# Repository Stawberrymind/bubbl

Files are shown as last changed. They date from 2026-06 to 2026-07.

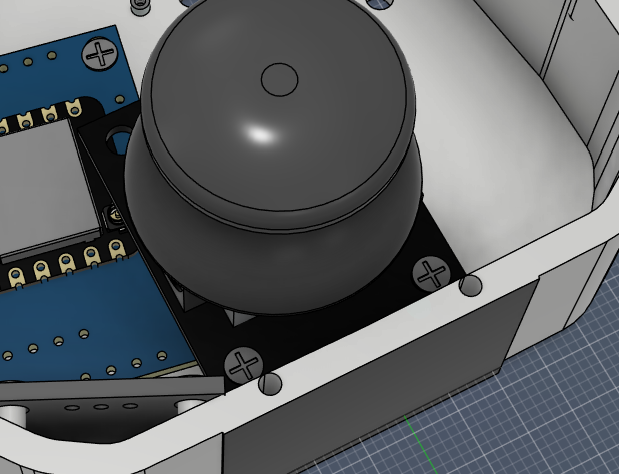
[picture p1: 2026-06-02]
Assets/assembly_2.png

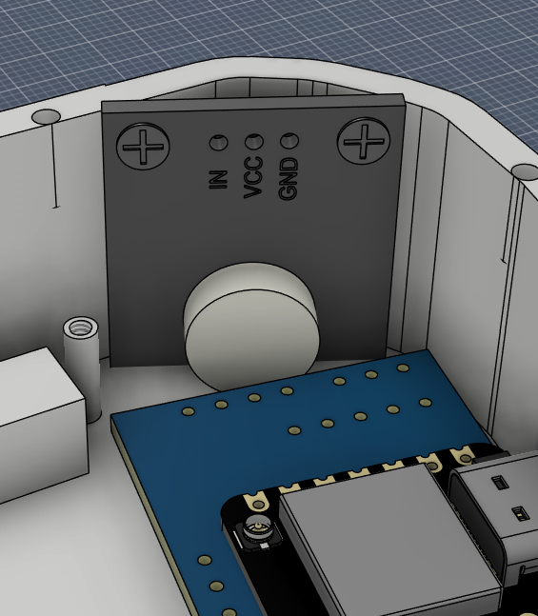
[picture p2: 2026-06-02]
Assets/assembly_1.png

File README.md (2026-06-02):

bubbl_assembled

# bubbl- A tamagotchi-inspired desk pet to keep friendships alive.

A friendship-powered Tamagotchi-inspired pet for your desk, which looks like a Japanese onigiri, keeps friend groups alive by maintaining a common pet and sending nudges to each other, just to keep the drifting friend group a little closer! 

## How does it work?
There is one shared pet for everyone. Every bubbl device in the same group (friend group) has the same pet, you can feed the pet, make it rest, and play with it. If no one in the friend group interacts with the pet, the pet's stats decay, causing harm to it :(, which incentivises the friend group to keep interacting with the pet. In the process, friends can send each other nudges, which are sound notifcations which also vibrate the device; this is useful when. This adds a fun component to the already interesting and interactive interconnected pet system. 

## Why did I make it?
In the current day and age, where friendships are basically just sending each other reels, friendships are dying fast. There is no real connection, and bubbl I hope helps solve that issue by having a pet to take care of; it makes sure all the members of the friend group have equal responsibility and are constantly reminded of each other, thus hopefully reducing friction in friendships.
 
## Components Required for the Build
I have listed everything in the project; you can find the same in the BOM

| No. | Quantity | Comment | Footprint | Link | Price | Total (USD) |
| ----- | --- | --- | --- | --- | ----- | --- |
| 1 | 1 | XIAO-ESP32-S3-SMD | XIAO-ESP32-S3-SMD | https://www.aliexpress.com/item/1005006987905528.html | 6.77  | 6.77 |
| 2 | 2 | 10uF | C0603 | https://jlcpcb.com/partdetail/HRE-CGA0805X5R106K500MT/C6119889 | 0.01  | 0.02 |
| 3 | 2 | 100nF | C0603 | https://jlcpcb.com/partdetail/39123-0805B104K500NT/C38141 | 0.01  | 0.02 |
| 4 | 1 | MAX98357A | \- | https://www.aliexpress.com/item/1005007003802663.html | 0.65  | 0.65 |
| 5 | 1 | INMP441 | \- | https://www.aliexpress.com/item/1005008870682636.html | 0.75  | 0.75 |
| 6 | 1 | 1.3" OLED | \- | https://www.aliexpress.com/item/1005008365029314.html | 2.03  | 2.03 |
| 7 | 1 | Analog Joystick Module | \- | https://www.aliexpress.com/item/1005012147405483.html | 1.92  | 1.92 |
| 8 | 1 |  Vibration Motor Module | \- | https://www.aliexpress.com/item/33009331080.html | 0.49  | 0.49 |
| 9 | 10 | M2 X 3mm Phillips Round head | \- | https://onlyscrews.in/products/m2-x-5mm-phillips-round-head-laptop-screw | 0.04  | 0.4 |
| 10 | 5 | M1.4 X 2mm Phillips Round head | \- | https://onlyscrews.in/products/m1-4-x-2mm-phillips-round-head-laptop-and-mobile-screw-dia-1-4mm-length-2mm | 0.023 | 0.115 |
| 11 | 6 | M2 X 10mm Hard Dowel Pins | \- | https://onlyscrews.in/products/m2-x-10mm-hard-dowel-pins-dia-2mm-length-10mm | 0.051 | 0.306 |
| 12 | 1 | 400mAh LiPo | \- | https://robu.in/product/400mah-pcm-protected-micro-li-po-battery-2/ | 2.86  | 2.86 |
| 13 | 5 | 2 Layer PCB | \- | https://cart.jlcpcb.com/quote?spm=jlcpcb.Public.2006 | 2.1 | 2.1 |
| Total | | | | | | 18.431 USD  |

## PCB and Schematic
I designed it in EasyEDA. You can find the Gerber files in the repo. The schematic is:

schematic

And the PCB is a 2-layer PCB with a ground plane as layer 2:

pcb

3D Render of the PCB:

pcb_3d

Wiring diagram:

wiring_diagram

## Case
Top and bottom view of the Case:

case_front_back

## Assembly 
Note: Please follow the wiring diagram :)
1. Take the bottom case and install the PCB, and screw it into the bottom case using a M2 x 3 mm screw. Before screwing it, wire the BAT+ and BAT- from LiPO to the PCB.

2. Screw in the Vibration motor after making the connections, as shown in the picture, using M2 x 3 mm

   assembly_1
 
3. Wire the Joystick Module to the PCB, then screw it in using M2 x 3 mm screws as shown in the picture.

   assembly_2

5. Screw in the Speaker, with the diaphragm facing outward towards the speaker holes, using a M2 X 3 mm screw as shown in the picture.
 
   assembly_3

6. Connect the amplifier to the microcontroller, then screw the amp into the case using  M1.4 x 2 mm screws as shown. Then connect the speaker to the amplifier.
   
   assembly_4
   
7. The bottom of the case should now look as shown below.
   
   assembly_5

8. Insert M2 x 10 mm hard metal dowel pins into the bottom case as shown below.
   
   assembly_6

9. Now it's time to assemble the top case, screw in the OLED to the underside of the top case using M2 x 3 mm screws as shown and wire it to the microcontroller.

   assembly_7

10. Install the INMP441 I2S Microphone with M1.4 x 2 mm screws into the case as shown and wire it to the microcontroller.
 
   assembly_8

11. Lower the top case onto the bottom one, applying firm pressure equally from all sides to make sure the top locks in with the bottom using the dowel pins.
12. Your own personal bubbl is now complete!

## Setting it up
Section I: Setting up Supabase:
1. Go to https://supabase.com/ and create a new account
2. Create a new project

   

4. Go to the SQL Editor Tab and paste the content of the bubbl_supabase file in Firmware into the editor

   

5. Run the script, which will lead to the creation of the following tables: pet, users, events, and nudges
6. In the SQL Editor, enter your friends' names in place of user1...4

7. Go to your Supabase settings, then to API and copy your:
   * Project URL
   * Anom public key

Section II: Setting up the firmware:

7.  In the bubbl.ino file, replace the SSID and password fields with your credentials, enter the Supabase URL and Anon Key below, and set up your name.
   * Note: All friends must use the same project
   * Be listed in the users table
   * Have a unique username

8. Install the required libraries and upload the firmware to bubbl

9. Wohooooo! You and your friend group now have a working bubbl of your own!

## Files
```text
    └── bubbl/
        ├── CAD_Files/
        │   ├── bubbl_case.step
        |   ├── bubbl.stl
        │   ├── bubbl_assembled.f3z
        │   └── bubbl_assembled.step
        ├── PCB_Files/
        │   ├── bubbl_gerber.zip
        │   └── bubbl_source.epro2
        ├── Firmware_Files/
        │   ├── bubbl.ino
        │   ├── bubbl_supabase.mdf
        │   └── bubbl.wav
        ├── bubbl_BOM.csv
        ├── bubbl_Zine.pdf
        └── README.md
        └── Assets/
        
```
## Future Additions
In upcoming software versions, I will include support to send short voice notes to your buddies!

## Credits

Abhinav [goat]

The idea: https://github.com/TaniWanKenobi/tamagotchi

Vibration motor module: https://grabcad.com/library/vibration-motors-1

OLED module: https://grabcad.com/library/oled-display-1-3-2

Amplifier: https://grabcad.com/library/max98357a-3w-i2s-amplifier-1

Microphone: https://grabcad.com/library/inmp441-microphone-module-1

Joystick: https://grabcad.com/library/dual-axis-xy-joystick-module-with-push-button-1

## Zine

bubbl_zine

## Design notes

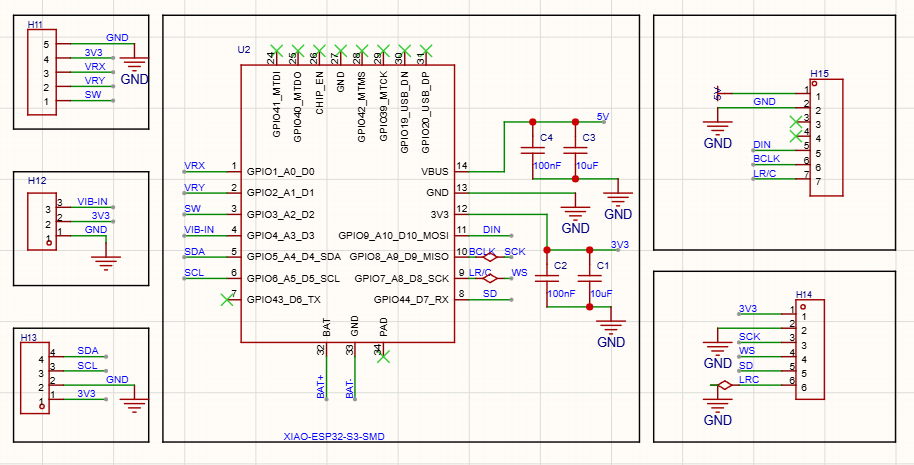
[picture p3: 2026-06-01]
Assets/schematic.png

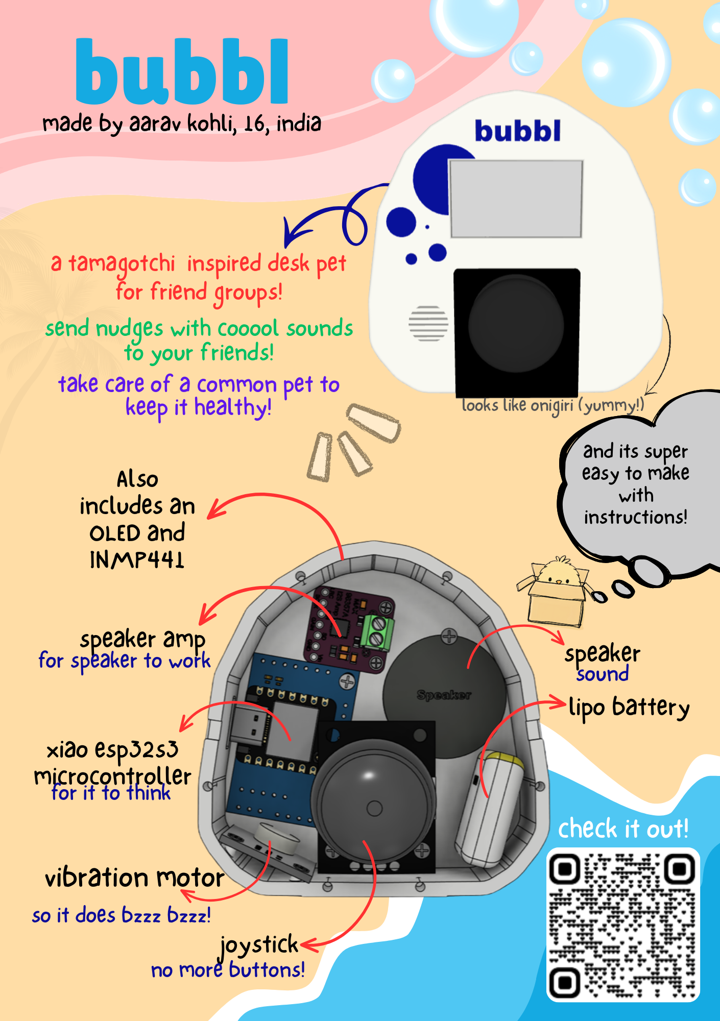
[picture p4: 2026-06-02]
Assets/bubbl_zine.png

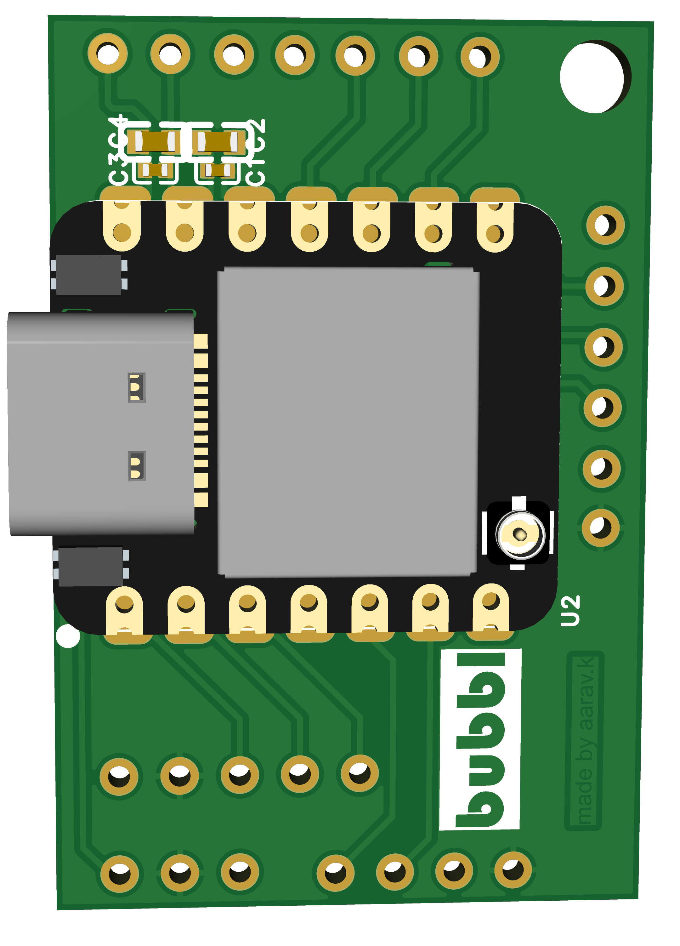
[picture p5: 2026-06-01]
Assets/pcb_3d.png

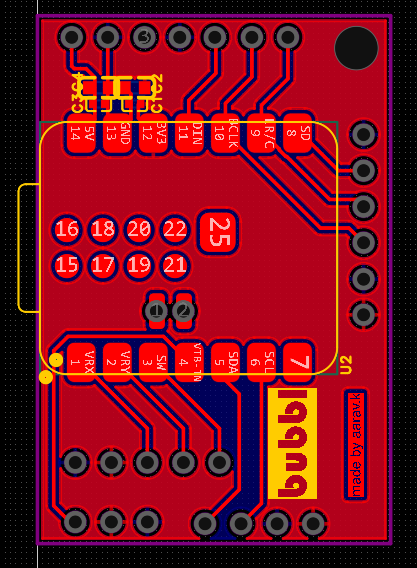
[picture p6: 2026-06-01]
Assets/pcb.png

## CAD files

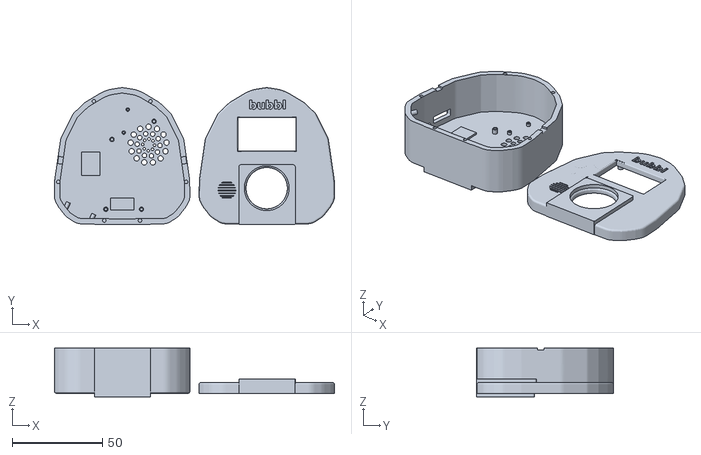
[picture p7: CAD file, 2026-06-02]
CAD_Files/bubbl.stl
154.9 x 75.6 x 27.0

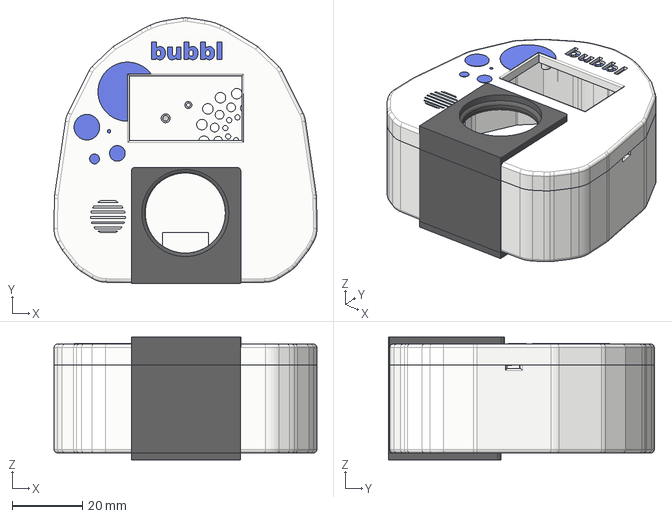
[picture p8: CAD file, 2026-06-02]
CAD_Files/bubbl_case.step
74.9 x 75.6 x 35.0 mm

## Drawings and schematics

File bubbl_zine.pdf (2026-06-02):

# bubbl

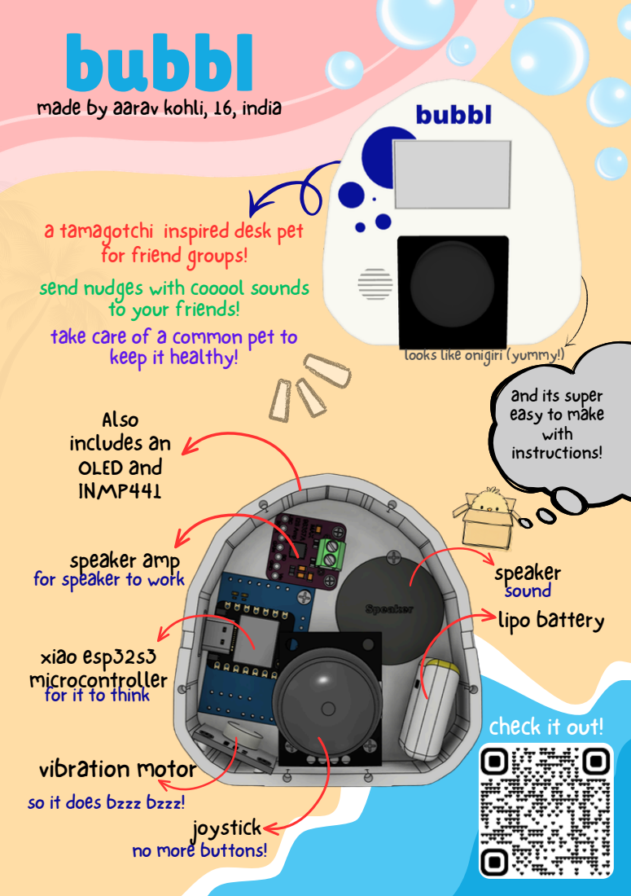
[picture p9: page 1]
joystick; speaker lipo battery; sound

made by aarav kohli, 16, india

a tamagotchi inspired desk pet
for friend groups!
send nudges with cooool sounds
to your friends!
take care of a common pet to
keep it healthy!
Also
includes an
OLED and
INMP441
speaker amp
for speaker to work
xiao esp32s3
microcontroller
for it to think
vibration motor
so it does bzzz bzzz!
no more buttons!

looks like onigiri (yummy!)

and its super
easy to make
with
instructions!

check it out!

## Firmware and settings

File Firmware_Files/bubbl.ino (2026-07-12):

// ============================================================================
//  bubbl — a tiny networked virtual pet for ESP32-S3
//  OLED (SSD1306) + analog joystick + Supabase backend + I2S audio
// ----------------------------------------------------------------------------
//  Highlights of this build:
//    * One reusable TLS-aware HTTP helper (no more copy-pasted boilerplate)
//    * Proper 2xx status + JSON error checking on every request
//    * Non-blocking WiFi connect with timeout + auto-reconnect
//    * Animated pet: blinking eyes, mood-driven mouth, subtle idle bob
//    * Graphical stat bars + live connection indicator
//    * Nudge notifications actually play a sound now
// ============================================================================

#include <Arduino.h>
#include <Wire.h>
#include <Adafruit_GFX.h>
#include <Adafruit_SSD1306.h>
#include <WiFi.h>
#include <WiFiClientSecure.h>
#include <HTTPClient.h>
#include <ArduinoJson.h>
#include <Fonts/Picopixel.h>
#include <Audio.h>
#include <SPIFFS.h>

// ---- Credentials -----------------------------------------------------------
const char* ssid          = "your_wifi_ssid";
const char* password      = "your_wifi_password";
const char* supabaseUrl   = "your_supabase_url";   // e.g. https://xxxx.supabase.co
const char* apiKey        = "your_supabase_api_key";

String username = "xyz_user";

// ---- Audio -----------------------------------------------------------------
Audio audio;
const char* NOTIFY_SOUND = "/bubbl.wav";   // file present in SPIFFS
bool playNotification = false;

// ---- Display ---------------------------------------------------------------
#define SCREEN_WIDTH  128
#define SCREEN_HEIGHT 64
Adafruit_SSD1306 display(SCREEN_WIDTH, SCREEN_HEIGHT, &Wire, -1);

// ---- Pins (ESP32-S3) -------------------------------------------------------
#define JOY_X   A0
#define JOY_Y   A1
#define JOY_BTN D2
#define I2C_SDA 5
#define I2C_SCL 6
#define I2S_BCLK 9
#define I2S_LRC  10
#define I2S_DIN  8

// ---- Timing (ms) -----------------------------------------------------------
const unsigned long updateDelay     = 60000;   // pet sync cooldown
const unsigned long pressDelay      = 250;
const unsigned long moveDelay       = 200;
const unsigned long frameDelay      = 33;      // ~30 fps
const unsigned long popupDuration   = 2000;
const unsigned long longPressDelay  = 700;
const unsigned long nudgeCheckDelay = 60000;
const unsigned long blinkInterval   = 3200;    // blink roughly every few seconds
const unsigned long blinkDuration   = 140;
const unsigned long wifiTimeout     = 15000;   // initial connect budget
const unsigned long wifiRetryDelay  = 10000;   // gap between reconnect attempts
const int           httpTimeout     = 5000;
const int           httpRetries     = 2;

// ---- HTTP joystick thresholds ----------------------------------------------
const int JOY_LOW  = 1200;
const int JOY_HIGH = 2800;

// ---- State flags -----------------------------------------------------------
bool firstSync          = true;
bool loadingPopup       = false;
bool lastButtonState    = HIGH;
bool longPressTriggered = false;

// ---- Model -----------------------------------------------------------------
struct Pet {
  int hunger;
  int happy;
  int energy;
  unsigned long age;
  int mood;       // 0 sad, 1 ok, 2 happy
};
Pet pet = {0, 0, 0, 0, 1};

struct Event { String text; };
Event events[5];
String users[10];

int eventCount    = 0;
int selectedEvent = 0;
int userCount     = 0;
int selectedUser  = 0;

// ---- Animation / scroll ----------------------------------------------------
unsigned long textScrollTimer = 0;
int  textScrollX = 0;

unsigned long lastUpdate      = 0;
unsigned long lastPrint       = 0;
unsigned long lastPress       = 0;
unsigned long lastMove        = 0;
unsigned long lastFrame       = 0;
unsigned long popupStart      = 0;
unsigned long buttonHoldStart = 0;
unsigned long lastNudgeCheck  = 0;
unsigned long lastWifiTry     = 0;
unsigned long blinkTimer      = 0;
bool          eyesClosed      = false;

// ---- Menu data -------------------------------------------------------------
const char* options[]   = {"Feed", "Rest", "Play"};
int selected = 1;
const int total = 3;
int xPositions[] = {2, 53, 103};

const char* petOptions[] = {"Stats", "Nudge", "Activity"};
int selectedPetOption = 0;
const int petTotal = 3;

enum Screen { MAIN, PET_MENU, STATS, ACTIVITY, NUDGE };
Screen currentScreen = MAIN;

enum Focus { MENU, PET };
Focus currentFocus = MENU;

String popupMessage = "";

// ---- Networking ------------------------------------------------------------
WiFiClientSecure secureClient;

// ---- Forward declarations --------------------------------------------------
void petSync(bool force = false);
void eventSync();
void fetchUsers();
void sendNudge();
void checkForNudges();
void connectWiFi();
void ensureWiFi();

// ============================================================================
//  HTTP helper — TLS-aware, retrying, with proper status reporting
// ============================================================================

// Performs a request against `path` (appended to supabaseUrl).
// Returns true only on a 2xx response. The body (if any) lands in `outBody`,
// and the final HTTP status code in `outCode`.
bool supabaseRequest(const char* method,
                     const String& path,
                     const String& body,
                     String& outBody,
                     int& outCode) {
  outBody = "";
  outCode = -1;

  if (WiFi.status() != WL_CONNECTED) {
    Serial.println("[HTTP] skipped — WiFi down");
    return false;
  }

  String url = String(supabaseUrl) + path;

  for (int attempt = 0; attempt <= httpRetries; attempt++) {
    HTTPClient http;
    if (!http.begin(secureClient, url)) {
      Serial.println("[HTTP] begin() failed");
      continue;
    }

    http.setTimeout(httpTimeout);
    http.addHeader("apikey", apiKey);
    http.addHeader("Authorization", "Bearer " + String(apiKey));
    if (body.length() > 0) {
      http.addHeader("Content-Type", "application/json");
    }

    int code;
    if (strcmp(method, "GET") == 0) {
      code = http.GET();
    } else if (strcmp(method, "POST") == 0) {
      code = http.POST(body);
    } else {
      code = http.sendRequest(method, (uint8_t*)body.c_str(), body.length());
    }

    outCode = code;
    if (code > 0) {
      outBody = http.getString();
    }
    http.end();

    Serial.printf("[HTTP] %s %s -> %d (try %d)\n",
                  method, path.c_str(), code, attempt + 1);

    if (code >= 200 && code < 300) return true;

    // Retry only on transient/connection failures, not on real HTTP errors.
    if (code > 0) return false;
    delay(150);
  }
  return false;
}

// Convenience wrapper: GET + JSON parse with error checking.
bool supabaseGetJson(const String& path, JsonDocument& doc) {
  String resp;
  int code;
  if (!supabaseRequest("GET", path, "", resp, code)) return false;

  DeserializationError err = deserializeJson(doc, resp);
  if (err) {
    Serial.print("[JSON] parse error: ");
    Serial.println(err.c_str());
    return false;
  }
  return true;
}

// ============================================================================
//  Drawing
// ============================================================================

void drawPopup() {
  if (loadingPopup) {
    display.fillRect(14, 20, 100, 20, WHITE);
    display.setTextColor(BLACK);
    display.setCursor(34, 27);
    display.print("Loading...");
    display.setTextColor(WHITE);
  } else if (millis() - popupStart < popupDuration) {
    display.fillRect(8, 20, 112, 20, WHITE);
    display.setTextColor(BLACK);
    display.setCursor(18, 27);
    display.print(popupMessage);
    display.setTextColor(WHITE);
  }
}

// Small WiFi indicator in the top-left corner.
void drawConnIcon() {
  bool up = (WiFi.status() == WL_CONNECTED);
  if (up) {
    // three rising bars
    display.fillRect(2, 6, 2, 2, WHITE);
    display.fillRect(5, 4, 2, 4, WHITE);
    display.fillRect(8, 2, 2, 6, WHITE);
  } else {
    // hollow bars + slash to signal offline
    display.drawRect(2, 6, 2, 2, WHITE);
    display.drawRect(5, 4, 2, 4, WHITE);
    display.drawLine(1, 8, 10, 1, WHITE);
  }
}

void drawBootScreen() {
  display.clearDisplay();
  display.setTextColor(WHITE);
  display.setTextSize(1);
  display.setCursor(5, 23);
  display.print("Bubbl is starting");
  display.setCursor(26, 33);
  display.print("Please wait..");
  display.display();
}

// Draws the animated face inside the main circle.
// `filled` = pet circle is highlighted (focused).
void drawPetFace(int cx, int cy, bool filled) {
  uint16_t bg = filled ? WHITE : BLACK;
  uint16_t fg = filled ? BLACK : WHITE;

  if (filled) display.fillCircle(cx, cy, 20, WHITE);
  else        display.drawCircle(cx, cy, 20, WHITE);

  int eyeY = cy - 4;
  int eyeDX = 7;

  if (eyesClosed) {
    // happy/sleepy closed eyes
    display.drawFastHLine(cx - eyeDX - 1, eyeY, 4, fg);
    display.drawFastHLine(cx + eyeDX - 2, eyeY, 4, fg);
  } else {
    display.fillRect(cx - eyeDX - 1, eyeY - 1, 2, 3, fg);
    display.fillRect(cx + eyeDX - 1, eyeY - 1, 2, 3, fg);
  }

  // Mouth reflects mood.
  int mouthY = cy + 7;
  if (pet.mood == 2) {
    // smile
    display.drawLine(cx - 6, mouthY,     cx - 3, mouthY + 2, fg);
    display.drawLine(cx - 3, mouthY + 2, cx + 3, mouthY + 2, fg);
    display.drawLine(cx + 3, mouthY + 2, cx + 6, mouthY,     fg);
  } else if (pet.mood == 1) {
    // flat
    display.drawFastHLine(cx - 5, mouthY + 1, 11, fg);
  } else {
    // frown
    display.drawLine(cx - 6, mouthY + 2, cx - 3, mouthY,     fg);
    display.drawLine(cx - 3, mouthY,     cx + 3, mouthY,     fg);
    display.drawLine(cx + 3, mouthY,     cx + 6, mouthY + 2, fg);
  }
  (void)bg;
}

void drawMainUI() {
  display.clearDisplay();

  drawConnIcon();

  display.setFont(&Picopixel);
  display.setTextColor(WHITE);
  display.setCursor(56, 4);
  display.print("bubbl");
  display.setFont();

  // Subtle idle bob: ±1px over a slow sine-ish cycle.
  int bob = ((millis() / 600) % 2 == 0) ? 0 : 1;
  drawPetFace(64, 28 + bob, currentFocus == PET);

  for (int i = 0; i < total; i++) {
    if (currentFocus == MENU && i == selected) {
      display.setTextColor(BLACK, WHITE);
    } else {
      display.setTextColor(WHITE);
    }
    display.setCursor(xPositions[i], 54);
    display.print(options[i]);
  }

  drawPopup();
  display.display();
}

void drawPetMainUI() {
  display.clearDisplay();
  display.setTextColor(WHITE);
  display.setCursor(38, 5);
  display.print("Pet Menu");

  for (int i = 0; i < petTotal; i++) {
    int y = 20 + (i * 12);
    if (i == selectedPetOption) {
      display.fillRect(18, y - 1, 92, 10, WHITE);
      display.setTextColor(BLACK);
    } else {
      display.setTextColor(WHITE);
    }
    display.setCursor(28, y);
    display.print(petOptions[i]);
  }

  drawPopup();
  display.display();
}

// Draws a labelled stat bar at row `y`.
void drawStatBar(int y, const char* label, int value) {
  display.setTextColor(WHITE);
  display.setCursor(2, y);
  display.print(label);

  int barX = 52, barW = 70, barH = 6;
  int barY = y - 1;
  display.drawRect(barX, barY, barW, barH, WHITE);

  int v = constrain(value, 0, 100);
  int fillW = (barW - 2) * v / 100;
  if (fillW > 0) display.fillRect(barX + 1, barY + 1, fillW, barH - 2, WHITE);
}

void drawStatsUI() {
  display.clearDisplay();
  display.setTextWrap(false);

  display.setTextColor(BLACK, WHITE);
  display.setCursor(5, 1);
  if (pet.mood == 0)      display.print(" Your pet is sad   ");
  else if (pet.mood == 1) display.print(" Your pet is ok    ");
  else                    display.print(" Your pet is happy ");

  drawStatBar(22, "Food", pet.hunger);
  drawStatBar(36, "Joy ", pet.happy);
  drawStatBar(50, "Pep ", pet.energy);

  drawPopup();
  display.display();
}

void drawActivityUI() {
  display.clearDisplay();
  display.setTextWrap(false);
  display.setTextColor(BLACK, WHITE);
  display.setCursor(0, 0);
  display.print("    Recent Actions    ");

  if (eventCount == 0) {
    display.setTextColor(WHITE);
    display.setCursor(18, 30);
    display.print("No activity yet");
  }

  for (int i = 0; i < eventCount; i++) {
    int y = 11 + (i * 10);
    bool selectedNow = (i == selectedEvent);
    String text = "> " + events[i].text;

    if (selectedNow) {
      display.fillRect(0, y - 1, 128, 9, WHITE);
      display.setTextColor(BLACK);

      int textWidth = text.length() * 6;
      if (textWidth > 128) {
        if (millis() - textScrollTimer > 120) {
          textScrollTimer = millis();
          textScrollX--;
          if (textScrollX < -(textWidth - 120)) textScrollX = 0;
        }
        display.setCursor(textScrollX + 2, y);
      } else {
        display.setCursor(0, y);
      }
    } else {
      display.setTextColor(WHITE);
      display.setCursor(0, y);
    }
    display.print(text);
  }

  drawPopup();
  display.display();
}

void drawNudgeUI() {
  display.clearDisplay();
  display.setTextColor(WHITE);
  display.setCursor(28, 5);
  display.print("Nudge Friend");

  if (userCount == 0) {
    display.setCursor(20, 30);
    display.print("No friends online");
  }

  for (int i = 0; i < userCount; i++) {
    int y = 20 + (i * 10);
    if (i == selectedUser) {
      display.fillRect(8, y - 1, 112, 9, WHITE);
      display.setTextColor(BLACK);
    } else {
      display.setTextColor(WHITE);
    }
    display.setCursor(16, y);
    display.print(users[i]);
  }

  drawPopup();
  display.display();
}

// ============================================================================
//  Pet logic
// ============================================================================

void petStatus() {
  if (pet.hunger < 30 || pet.happy < 30 || pet.energy < 30) {
    pet.mood = 0;
  } else if (pet.hunger > 65 && pet.happy > 65 && pet.energy > 65) {
    pet.mood = 2;
  } else {
    pet.mood = 1;
  }
  Serial.print("[PET] mood: ");
  Serial.println(pet.mood);
}

// Advances the blink animation. Call every frame.
void updateBlink() {
  unsigned long now = millis();
  if (!eyesClosed && now - blinkTimer > blinkInterval) {
    eyesClosed = true;
    blinkTimer = now;
  } else if (eyesClosed && now - blinkTimer > blinkDuration) {
    eyesClosed = false;
    blinkTimer = now;
  }
}

// ============================================================================
//  WiFi
// ============================================================================

void connectWiFi() {
  Serial.print("[WiFi] connecting to ");
  Serial.println(ssid);

  WiFi.mode(WIFI_STA);
  WiFi.begin(ssid, password);

  unsigned long start = millis();
  while (WiFi.status() != WL_CONNECTED && millis() - start < wifiTimeout) {
    Serial.print(".");
    delay(250);
  }
  Serial.println();

  if (WiFi.status() == WL_CONNECTED) {
    Serial.print("[WiFi] connected, IP: ");
    Serial.println(WiFi.localIP());
  } else {
    Serial.println("[WiFi] connect timed out — will keep retrying");
  }
  lastWifiTry = millis();
}

// Non-blocking reconnect: nudges WiFi back up without freezing the UI.
void ensureWiFi() {
  if (WiFi.status() == WL_CONNECTED) return;
  if (millis() - lastWifiTry < wifiRetryDelay) return;

  Serial.println("[WiFi] reconnecting...");
  WiFi.disconnect();
  WiFi.begin(ssid, password);
  lastWifiTry = millis();
}

// ============================================================================
//  Backend calls
// ============================================================================

void callFunction(String functionName) {
  Serial.print("[RPC] ");
  Serial.println(functionName);

  loadingPopup = true;
  if (currentScreen == MAIN)       drawMainUI();
  else if (currentScreen == STATS) drawStatsUI();

  String body = "{\"user_name\":\"" + username + "\"}";
  String resp;
  int code;
  bool ok = supabaseRequest("POST", "/rest/v1/rpc/" + functionName, body, resp, code);

  loadingPopup = false;
  popupMessage = ok ? "Success!" : "Server Error";
  popupStart   = millis();
}

void feedPet() { Serial.println("[ACT] feed"); callFunction("feed_pet"); petSync(true); }
void restPet() { Serial.println("[ACT] rest"); callFunction("rest_pet"); petSync(true); }
void playPet() { Serial.println("[ACT] play"); callFunction("play_pet"); petSync(true); }

void petSync(bool force) {
  if (!force && !firstSync && millis() - lastUpdate < updateDelay) {
    Serial.println("[SYNC] skipped (cooldown)");
    return;
  }
  firstSync  = false;
  lastUpdate = millis();

  DynamicJsonDocument doc(2048);
  if (!supabaseGetJson("/rest/v1/pet?id=eq.1&select=*", doc)) {
    Serial.println("[SYNC] pet sync failed");
    return;
  }

  JsonObject petData = doc[0];
  if (petData.isNull()) {
    Serial.println("[SYNC] empty pet payload");
    return;
  }

  pet.hunger = petData["hunger"]    | pet.hunger;
  pet.happy  = petData["happiness"] | pet.happy;
  pet.energy = petData["energy"]    | pet.energy;

  Serial.printf("[SYNC] hunger=%d happy=%d energy=%d\n",
                pet.hunger, pet.happy, pet.energy);
  petStatus();
}

void eventSync() {
  Serial.println("[EVT] sync");
  loadingPopup = true;
  drawActivityUI();

  DynamicJsonDocument doc(2048);
  bool ok = supabaseGetJson("/rest/v1/recent_events?select=*&limit=5", doc);
  loadingPopup = false;
  if (!ok) { Serial.println("[EVT] failed"); return; }

  eventCount = 0;
  for (JsonObject item : doc.as<JsonArray>()) {
    if (eventCount >= 5) break;

    String eventUser = item["username"].as<String>();
    String action    = item["action"].as<String>();
    String ago       = item["time_ago"].as<String>();

    String actionText;
    if (action == "feed")      actionText = "fed";
    else if (action == "rest") actionText = "rested";
    else                       actionText = "played with";

    events[eventCount].text =
      "\"" + eventUser + "\" " + actionText + " your bubbl (" + ago + ")";

    Serial.printf("[EVT] %d: %s\n", eventCount, events[eventCount].text.c_str());
    eventCount++;
  }
}

void fetchUsers() {
  Serial.println("[USR] fetch");

  DynamicJsonDocument doc(2048);
  if (!supabaseGetJson("/rest/v1/users?select=username", doc)) {
    Serial.println("[USR] failed");
    return;
  }

  userCount = 0;
  for (JsonObject item : doc.as<JsonArray>()) {
    if (userCount >= 10) break;
    String fetchedUser = item["username"].as<String>();
    if (fetchedUser != username) {
      users[userCount] = fetchedUser;
      Serial.print("[USR] + ");
      Serial.println(users[userCount]);
      userCount++;
    }
  }
  Serial.printf("[USR] %d loaded\n", userCount);
}

void sendNudge() {
  if (userCount == 0) { Serial.println("[NDG] no users"); return; }

  Serial.print("[NDG] -> ");
  Serial.println(users[selectedUser]);

  String body = "{\"sender\":\"" + username +
                "\",\"receiver\":\"" + users[selectedUser] + "\"}";
  String resp;
  int code;
  bool ok = supabaseRequest("POST", "/rest/v1/nudges", body, resp, code);

  popupMessage = ok ? "Buzz Sent!" : "Buzz Failed!";
  popupStart   = millis();
}

void checkForNudges() {
  if (millis() - lastNudgeCheck < nudgeCheckDelay) return;
  lastNudgeCheck = millis();

  if (WiFi.status() != WL_CONNECTED) {
    Serial.println("[NDG] check skipped — WiFi down");
    return;
  }
  Serial.println("[NDG] checking inbox");

  String path = "/rest/v1/nudges?receiver=eq." + username +
                "&seen=eq.false&order=created_at.desc&limit=1";

  DynamicJsonDocument doc(1024);
  if (!supabaseGetJson(path, doc)) { Serial.println("[NDG] check failed"); return; }

  JsonArray arr = doc.as<JsonArray>();
  if (arr.size() == 0) return;

  JsonObject nudge = arr[0];
  String sender = nudge["sender"].as<String>();
  long   nudgeId = nudge["id"] | -1;

  popupMessage     = "\"" + sender + "\" nudged you";
  popupStart       = millis();
  playNotification = true;     // <- actually trigger the sound now
  Serial.println("[NDG] received!");

  if (nudgeId >= 0) {
    String seenPath = "/rest/v1/nudges?id=eq." + String(nudgeId);
    String resp;
    int code;
    supabaseRequest("PATCH", seenPath, "{\"seen\":true}", resp, code);
  }
}

// ============================================================================
//  Input
// ============================================================================
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
void loop() {
  audio.loop();

  if (playNotification) {
    audio.connecttoFS(SPIFFS, NOTIFY_SOUND);
    playNotification = false;
  }

  handleJoystick();
  handleBtn();
  ensureWiFi();
  checkForNudges();

  if (millis() - lastFrame >= frameDelay) {
    lastFrame = millis();
    updateBlink();

    switch (currentScreen) {
      case MAIN:     drawMainUI();    break;
      case PET_MENU: drawPetMainUI(); break;
      case STATS:    drawStatsUI();   break;
      case ACTIVITY: drawActivityUI();break;
      case NUDGE:    drawNudgeUI();   break;
    }
  }

  if (millis() - lastPrint > 2500) {
    lastPrint = millis();
    Serial.println("[hb] alive");
  }
}

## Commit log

2026-05-31 Initialize README for 2SB USB-C Flash Drive project
    Added detailed documentation for the 2SB USB-C Flash Drive project, including components, assembly instructions, and setup.
2026-06-01 Added repo files
    [bubbl_BOM.csv]
2026-06-01 Revise README with accurate component and assembly info
    Updated the README to correct component details, PCB specifications, and assembly instructions.
2026-06-02 Revise components list and update total cost
    Updated the components list with new items and prices, including a 400mAh LiPo battery.
2026-06-02 Edited folders and added zine
    [bubbl.stl, bubbl_BOM.csv, bubbl_case.step]
2026-06-02 Renumber assembly steps in README
    Renumber assembly steps in README for clarity and consistency.
2026-06-02 Add wiring diagram to README
    Added wiring diagram image to README.
